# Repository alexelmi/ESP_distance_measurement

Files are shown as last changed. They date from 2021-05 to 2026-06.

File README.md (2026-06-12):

# Distance Measurement

A tiny handheld ultrasonic "distance radar" built on a WeMos D1 mini. The closer
you hold it to an object, the faster it blinks and beeps.

> This tiny project I made with my daughter. When she came to me asking for a
> little handheld which is peeping and blinking, I thought using an ultrasonic
> sensor could be fun.

So I sat down and designed the circuit and the PCB in KiCad:

| Schematic | PCB | 3D view |
|---|---|---|
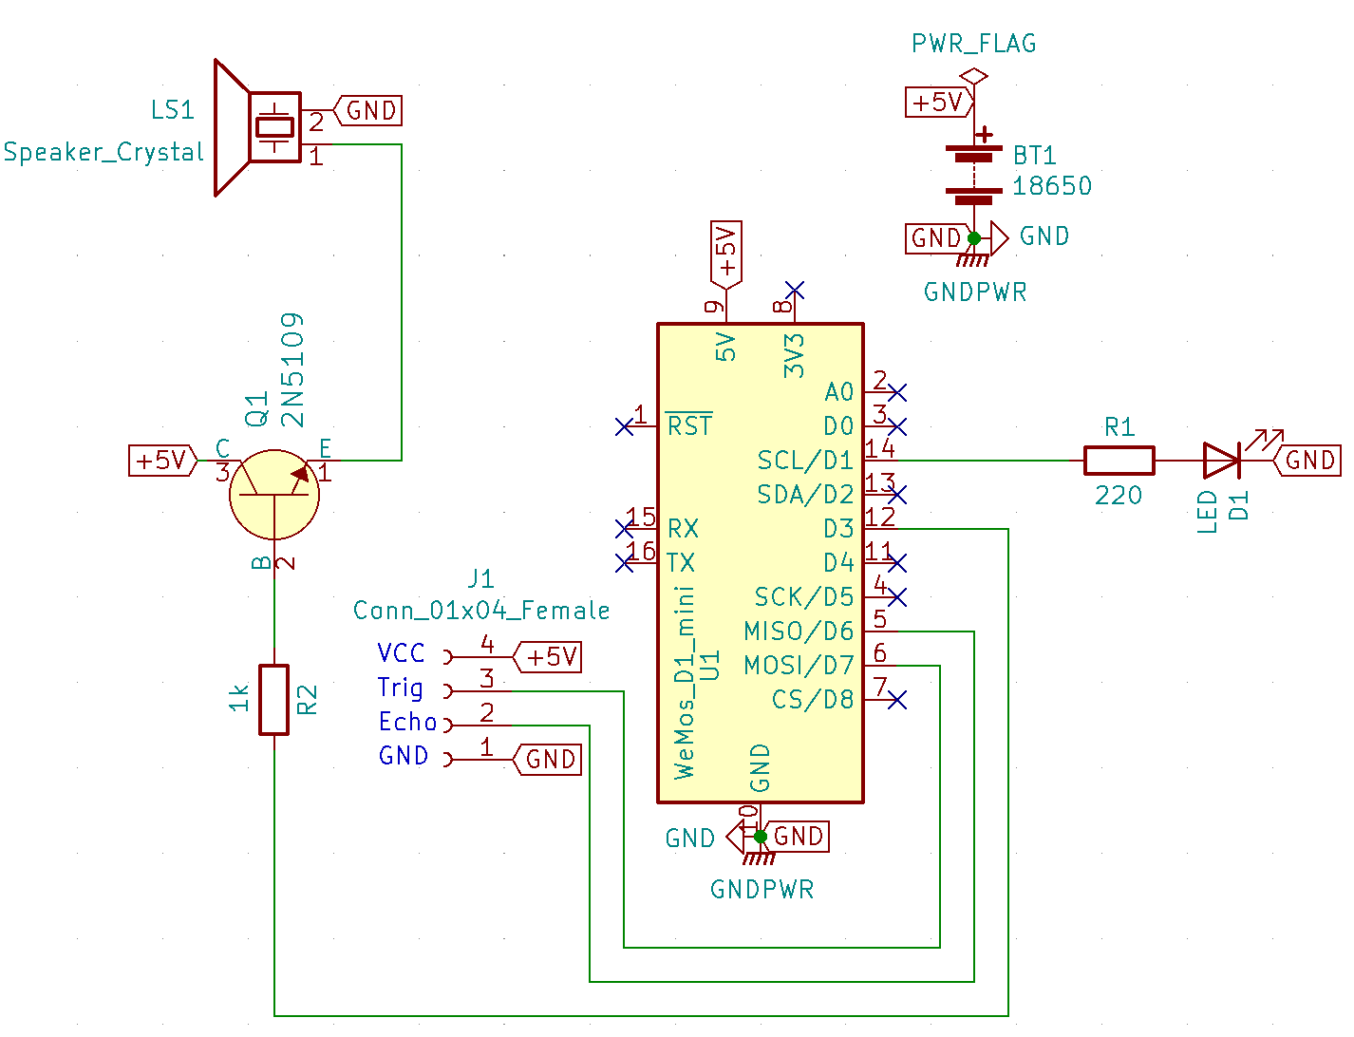
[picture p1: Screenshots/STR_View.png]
Schematic
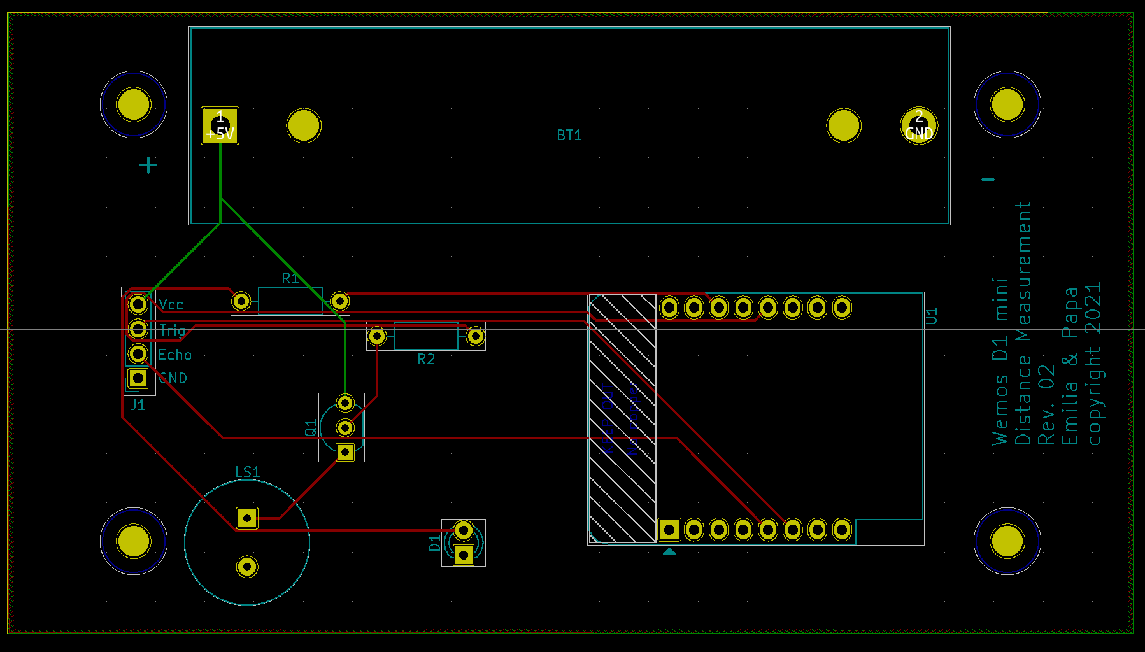
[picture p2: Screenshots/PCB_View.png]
PCB
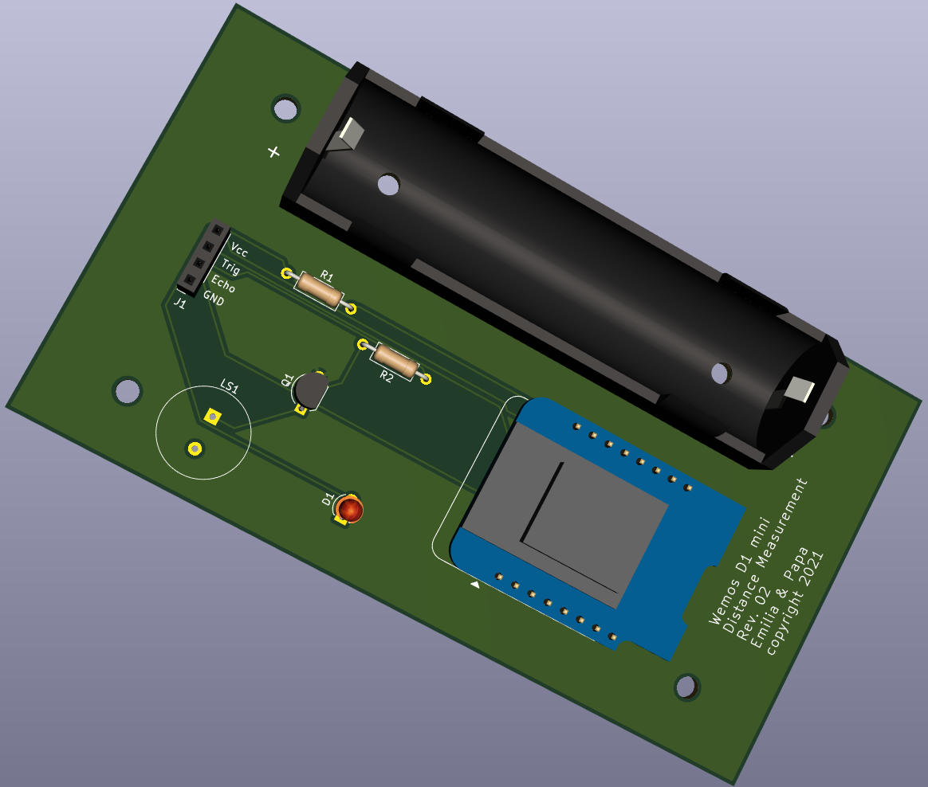
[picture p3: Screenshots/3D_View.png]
3D
|  |  |  |

The next day we put the components together and loaded the first test sketch onto
the WeMos D1 mini. (I have to admit I didn't test it before. 🙂)

## Features

- Ultrasonic distance measurement (~2 cm … 5 m) with an HC-SR04.
- LED + buzzer feedback that speeds up as the object gets closer; **solid** when
  very close and **silent** when nothing is in range.
- Distance also printed over `Serial` at 115200 baud.

## Hardware at a glance

| Function | WeMos label | ESP8266 GPIO |
|---|---|---|
| Ultrasonic Trigger | D7 | GPIO13 |
| Ultrasonic Echo | D6 | GPIO12 |
| LED | D1 | GPIO5 |
| Buzzer (via transistor) | D3 | GPIO0 |

Full BOM, schematic, PCB and Gerbers are in [`Hardware/`](Hardware/). Pin mapping
verified against the KiCad netlist.

## Software

The code was built up from small test sketches, then combined into the final
firmware:

- **Ultrasonic test sketch** — [`Software/Test_UltraSonic_Simple`](Software/Test_UltraSonic_Simple) — prints the measured distance.
- **LED blink test sketch** — [`Software/Test_LED_Simple`](Software/Test_LED_Simple).
- **Buzzer beep test sketch** — [`Software/Test_Buzzer_Simple`](Software/Test_Buzzer_Simple).
- **Final firmware** — [`Software/Final_Software`](Software/Final_Software) — sensor + LED + buzzer combined.

### Quick start

1. Install the Arduino IDE and add ESP8266 board support
   (`https://arduino.esp8266.com/stable/package_esp8266com_index.json`).
2. Select board **LOLIN(WEMOS) D1 R2 & mini**.
3. Open `Software/Final_Software/Final_Software.ino`, upload, and open the Serial
   Monitor at **115200 baud**.

Step-by-step instructions are in the [full documentation](docs/DOCUMENTATION.md).

## Tests

The firmware's distance/beep logic is unit-tested on the host (no hardware
needed):

```sh
cd Software/Tests
c++ -std=c++11 -Wall -Wextra test_distance_logic.cpp -o test_distance_logic
./test_distance_logic
```

## Documentation

- 📘 [Full documentation](docs/DOCUMENTATION.md) — theory, hardware, firmware,
  build & flash, troubleshooting.
- 🛠️ [Work report](WORK_REPORT.md) — bugs fixed and improvements made.
- ✅ [Tests README](Software/Tests/README.md).

## License

See [LICENSE](LICENSE).

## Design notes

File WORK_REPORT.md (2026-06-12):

# Work Report — Code review, fixes, tests & docs

This report documents a review-and-improvement pass over the
`ESP_distance_measurement` project: the bugs found, the changes made, the test
suite added, and the documentation written.

## 1. Scope

- Reviewed all firmware sketches under `Software/`.
- Cross-checked the firmware pin assignments against the hardware
  (`Hardware/KiCad_Files/Distance_Measurement_V2.net`).
- Implemented fixes and improvements.
- Added a host-side test suite and ran it.
- Wrote full documentation and rebuilt the README.

## 2. Bugs found & fixed

### 2.1 Continuous beeping when nothing is in range *(functional bug)*

`pulseIn()` returns `0` on timeout (no echo). The old `Final_Software` computed
`distanceCM = 0`, which fell into the `distanceCM <= 9` branch → `waiting = 0` →
the LED and buzzer were driven continuously. **Result:** the device beeped
non-stop whenever nothing was in front of it.

**Fix:** `echoToDistanceCm()` now returns a `NO_MEASUREMENT` sentinel for a
timeout or any reading outside ~2 cm…5 m, and `loop()` stays silent in that case.
Covered by a regression test.

### 2.2 Trigger pulse 1000× too long *(spec violation)*

The HC-SR04 expects a **10 µs** HIGH pulse on `TRIG`. Both the final and the
ultrasonic test sketch used `delay(10)` — i.e. **10 ms** — plus a leading
`delay(5)`. It happened to work but stretched every loop and is out of spec.

**Fix:** replaced with `delayMicroseconds(2)` / `delayMicroseconds(10)`, and gave
`pulseIn()` an explicit 30 ms timeout (~5 m) so a missing echo no longer blocks.

### 2.3 Wrong Echo pin in the ultrasonic test sketch *(hardware mismatch)*

`Test_UltraSonic_Simple` used `pinEcho = 15` (GPIO15). The KiCad netlist shows
GPIO15 is **not** wired to the sensor on this PCB — the sensor's Echo line is on
**GPIO12**. The test sketch therefore could not work on the actual board.

**Fix:** set `pinEcho = 12` to match the PCB, with a comment explaining why.

*(The `Final_Software` pin assignments — Trig 13, Echo 12, LED 5, Buzzer 0 — were
verified **correct** against the netlist and left unchanged.)*

## 3. Improvements

- **Replaced the ~60-line if/else ladder** that mapped distance → beep interval
  with a compact, ordered lookup table (`distanceToWaitingMs()`), removing the
  repeated `Serial.print` blocks and any risk of coverage gaps.
- **Extracted the pure logic** into `Software/Final_Software/distance_logic.h`
  (no Arduino dependencies) so the maths is unit-testable on a PC. The sketch
  `#include`s it.
- **"Very close" now means a solid tone/light** instead of `waiting = 0`, which
  previously toggled with no delay and was effectively invisible.
- **Named constants** for the speed of sound, valid range and echo timeout.
- Minor cleanups: consistent naming (`buzzerPin`), `digitalWrite(TRIG, LOW)` in
  `setup()`, float division in the distance maths, trailing newlines.

## 4. Tests

Added `Software/Tests/test_distance_logic.cpp` — a dependency-free C++ test
runner that exercises the exact firmware logic on the host.

```
$ c++ -std=c++11 -Wall -Wextra test_distance_logic.cpp -o test_distance_logic
$ ./test_distance_logic
...
21 checks, 0 failure(s)
ALL TESTS PASSED
```

Coverage: echo→distance conversion, the timeout/out-of-range regression cases,
every row of the distance→interval table, and a monotonicity property (the beep
interval never increases as the target gets closer).

## 5. Documentation

- **`docs/DOCUMENTATION.md`** — full project documentation: overview, theory of
  operation, BOM, verified pin-mapping table, schematic/PCB/3D images, firmware
  guide, build & flash steps, the beep-interval table, tests, and
  troubleshooting.
- **`Software/Tests/README.md`** — how to build and run the tests.
- **`readme.md`** — rebuilt: keeps the original story and adds features,
  hardware summary, quick start, and links to the docs and tests.
- **`.gitignore`** — ignores the compiled test binary.

## 6. Files changed / added

| File | Change |
|---|---|
| `Software/Final_Software/Final_Software.ino` | Rewritten (fixes + refactor) |
| `Software/Final_Software/distance_logic.h` | **New** — testable pure logic |
| `Software/Test_UltraSonic_Simple/Test_UltraSonic_Simple.ino` | Echo pin + trigger timing fix |
| `Software/Tests/test_distance_logic.cpp` | **New** — unit tests |
| `Software/Tests/README.md` | **New** |
| `docs/DOCUMENTATION.md` | **New** |
| `WORK_REPORT.md` | **New** — this file |
| `readme.md` | Rebuilt |
| `.gitignore` | Ignore test binary |

## 7. Not changed (and why)

- **Hardware files** (KiCad, Gerbers, PDFs, Fritzing) — out of scope; the review
  only used them to verify pin assignments.
- **`Final_Software` pin numbers** — already correct per the netlist.
- The firmware could not be compiled with `arduino-cli` (not installed in this
  environment); correctness was instead verified through the host-side tests of
  the extracted logic.

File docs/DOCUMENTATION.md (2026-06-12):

# ESP Distance Measurement — Full Documentation

A small handheld ultrasonic "distance radar" built on a WeMos D1 mini (ESP8266).
The closer an object is, the faster an LED blinks and a buzzer beeps. It started
as a weekend project to build together with my daughter.

- [1. Overview](#1-overview)
- [2. How it works](#2-how-it-works)
- [3. Hardware](#3-hardware)
  - [3.1 Bill of materials](#31-bill-of-materials)
  - [3.2 Pin mapping](#32-pin-mapping)
  - [3.3 Schematic, PCB and 3D view](#33-schematic-pcb-and-3d-view)
- [4. Firmware](#4-firmware)
  - [4.1 Sketches](#41-sketches)
  - [4.2 Distance → beep interval](#42-distance--beep-interval)
  - [4.3 Build & flash](#43-build--flash)
- [5. Tests](#5-tests)
- [6. Troubleshooting](#6-troubleshooting)
- [7. Changes & fixes](#7-changes--fixes)

---

## 1. Overview

| | |
|---|---|
| **Microcontroller** | WeMos D1 mini (ESP8266) |
| **Sensor** | HC-SR04 ultrasonic range finder |
| **Outputs** | LED + piezo buzzer (driven via an NPN transistor) |
| **Range** | ~2 cm … 5 m |
| **Power** | 5 V (battery `BT1` / USB) |
| **Firmware** | Arduino sketch, `Serial` at 115200 baud |

The behaviour: every loop the firmware fires one ultrasonic ping, converts the
echo time to a distance, and translates that distance into a blink/beep
interval. Far away → slow beep. Very close → solid tone. Nothing in range →
silent.

## 2. How it works

An HC-SR04 measures distance by emitting a 40 kHz ultrasonic burst and timing
how long the echo takes to return:

1. The MCU pulses `TRIG` HIGH for **10 µs**.
2. The sensor emits 8 ultrasonic cycles and raises `ECHO`.
3. `ECHO` stays HIGH for the round-trip travel time of the sound.
4. Distance = `(echo_time / 2) × speed_of_sound`.

With the speed of sound ≈ 343.2 m/s = **0.03432 cm/µs**:

```
distance_cm = (echo_time_µs / 2) × 0.03432
```

If no echo returns, `pulseIn()` times out and returns `0`. The firmware treats
that (and any reading outside ~2 cm…5 m) as **"no measurement"** and stays quiet,
rather than mistaking it for a zero-centimetre object.

## 3. Hardware

### 3.1 Bill of materials

| Ref | Part | Notes |
|-----|---|---|
| `U1` | WeMos D1 mini (ESP8266) | Main controller |
| `J1` | 4-pin header | HC-SR04 connector: GND / Echo / Trig / 5V |
| `D1` | LED | Visual indicator |
| `R1` | Resistor | LED series resistor |
| `Q1` | NPN transistor | Buzzer driver |
| `R2` | Resistor | Transistor base resistor |
| `LS1` | Piezo buzzer (PS1240) | Audible indicator |
| `BT1` | Battery / 5 V supply | Power input |

*(Refs taken from the KiCad netlist `Hardware/KiCad_Files/Distance_Measurement_V2.net`.)*

### 3.2 Pin mapping

Verified against the KiCad netlist. **Use these in the firmware.**

| Function | WeMos label | ESP8266 GPIO | Driven via |
|---|---|---|---|
| Ultrasonic **Trigger** | D7 | **GPIO13** | direct to `J1` |
| Ultrasonic **Echo** | D6 | **GPIO12** | direct from `J1` |
| **LED** | D1 | **GPIO5** | `R1` |
| **Buzzer** | D3 | **GPIO0** | `R2` → `Q1` → `LS1` |

> **Note on GPIO0 (buzzer):** GPIO0 is a boot-strapping pin on the ESP8266. It
> must be HIGH at power-up to boot from flash. The transistor base sits behind
> `R2`, so the pin is free to float high at boot — but if you ever rewire the
> buzzer, keep this constraint in mind.

> **Note on the HC-SR04 connector `J1`:** the header order is
> `GND · Echo(GPIO12) · Trig(GPIO13) · 5V`. Make sure the sensor is plugged in
> with matching orientation (sensor pinout is `VCC · Trig · Echo · GND`).

### 3.3 Schematic, PCB and 3D view

| Schematic | PCB | 3D |
|---|---|---|
| Schematic | PCB | 3D |

Source files:
- KiCad project: `Hardware/KiCad_Files/`
- Gerbers (V2): `Hardware/Gerber_Distance_Measurement_V2/`
- Circuit diagram PDFs: `Hardware/Circuit Diagram/`
- Interactive BOM: `Hardware/bom/ibom.html`
- Fritzing layout: `Hardware/Fritzing/`

## 4. Firmware

### 4.1 Sketches

| Sketch | Purpose |
|---|---|
| `Software/Test_LED_Simple/` | Blink the LED only (GPIO5). |
| `Software/Test_Buzzer_Simple/` | Beep the buzzer only (GPIO0). |
| `Software/Test_UltraSonic_Simple/` | Print measured distance over `Serial`. |
| `Software/Final_Software/` | The complete device (sensor + LED + buzzer). |

The final sketch keeps its pure logic in
[`distance_logic.h`](../Software/Final_Software/distance_logic.h) so it can be
unit-tested off-device (see [Tests](#5-tests)).

### 4.2 Distance → beep interval

`distanceToWaitingMs()` maps a distance to the LED/buzzer half-period:

| Distance (cm) | Half-period (ms) | Feel |
|---:|---:|---|
| 400 … 500 | 1000 | very slow |
| 300 … 399 | 800 | |
| 200 … 299 | 700 | |
| 100 … 199 | 500 | |
| 80 … 99 | 400 | |
| 60 … 79 | 300 | |
| 40 … 59 | 200 | |
| 20 … 39 | 100 | |
| 10 … 19 | 50 | fast |
| 2 … 9 | 0 | **solid** tone/light |
| no echo / >5 m | — | **silent** |

### 4.3 Build & flash

1. Install the [Arduino IDE](https://www.arduino.cc/en/software).
2. Add ESP8266 board support: **File → Preferences → Additional Boards Manager
   URLs** → `https://arduino.esp8266.com/stable/package_esp8266com_index.json`,
   then install **esp8266** in the Boards Manager.
3. Select board **LOLIN(WEMOS) D1 R2 & mini**.
4. Open `Software/Final_Software/Final_Software.ino`.
5. Upload, then open the Serial Monitor at **115200 baud**.

## 5. Tests

The conversion and mapping logic is covered by host-side unit tests — no
hardware required:

```sh
cd Software/Tests
c++ -std=c++11 -Wall -Wextra test_distance_logic.cpp -o test_distance_logic
./test_distance_logic
```

See [`Software/Tests/README.md`](../Software/Tests/README.md) for what is
covered.

## 6. Troubleshooting

| Symptom | Likely cause |
|---|---|
| Always "No reading" | Echo not on GPIO12 / sensor connector reversed / no 5 V to sensor. |
| Device beeps non-stop with nothing in front | Old firmware (pre-fix). Reflash the current `Final_Software`. |
| Board won't boot / hangs at power-up | Something holding GPIO0 LOW at boot (buzzer wiring). |
| Distances jump around | Soft/angled/small targets reflect poorly; aim at a flat surface. |
| Nothing on Serial | Wrong baud rate — set the monitor to 115200. |

## 7. Changes & fixes

A detailed log of the bug fixes and improvements made to the firmware is in
[`WORK_REPORT.md`](../WORK_REPORT.md).

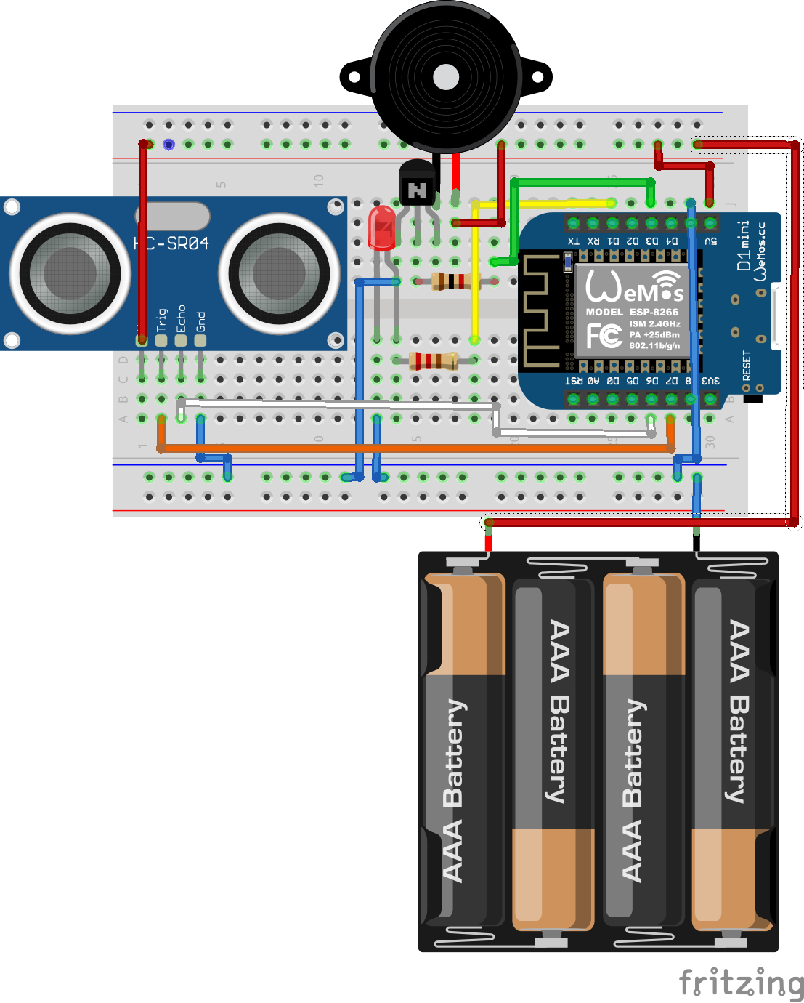
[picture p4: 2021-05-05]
Hardware/Fritzing/Layout.png

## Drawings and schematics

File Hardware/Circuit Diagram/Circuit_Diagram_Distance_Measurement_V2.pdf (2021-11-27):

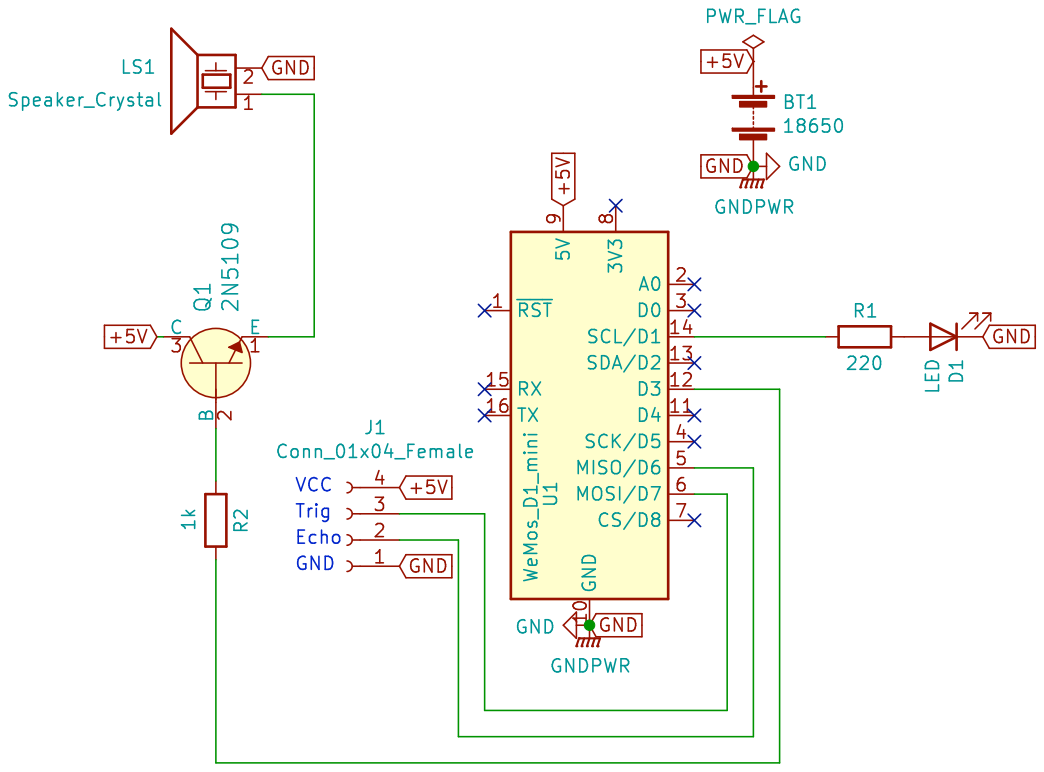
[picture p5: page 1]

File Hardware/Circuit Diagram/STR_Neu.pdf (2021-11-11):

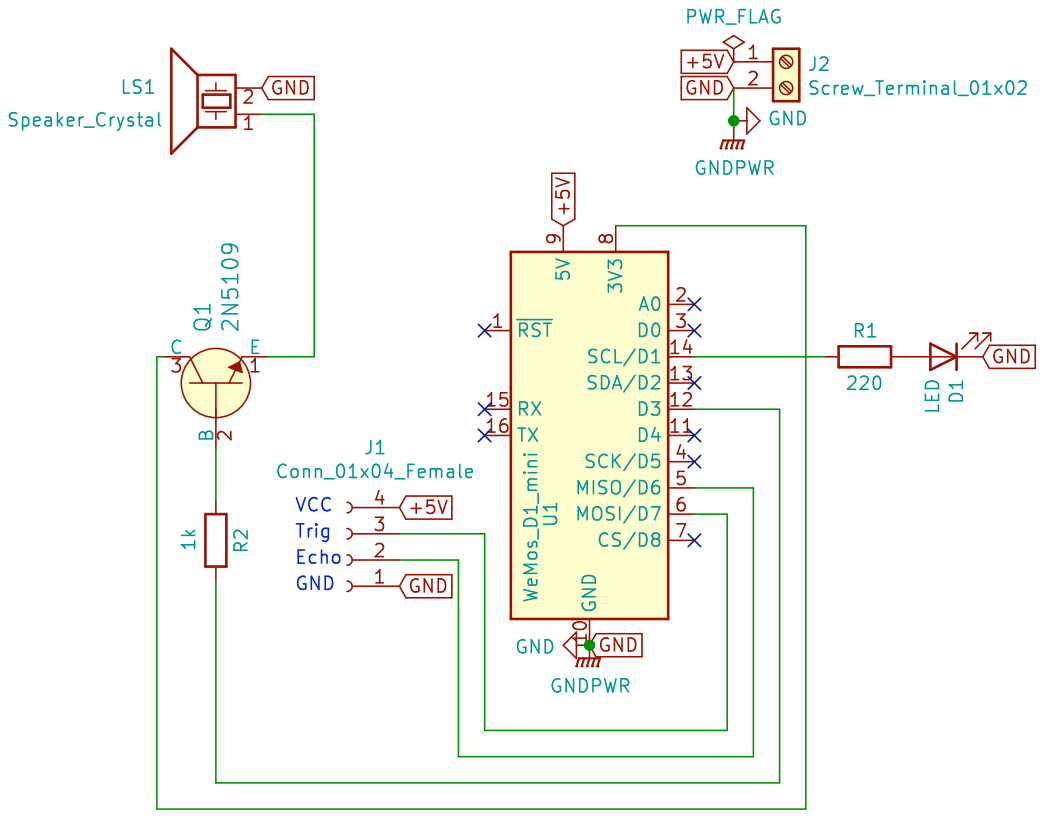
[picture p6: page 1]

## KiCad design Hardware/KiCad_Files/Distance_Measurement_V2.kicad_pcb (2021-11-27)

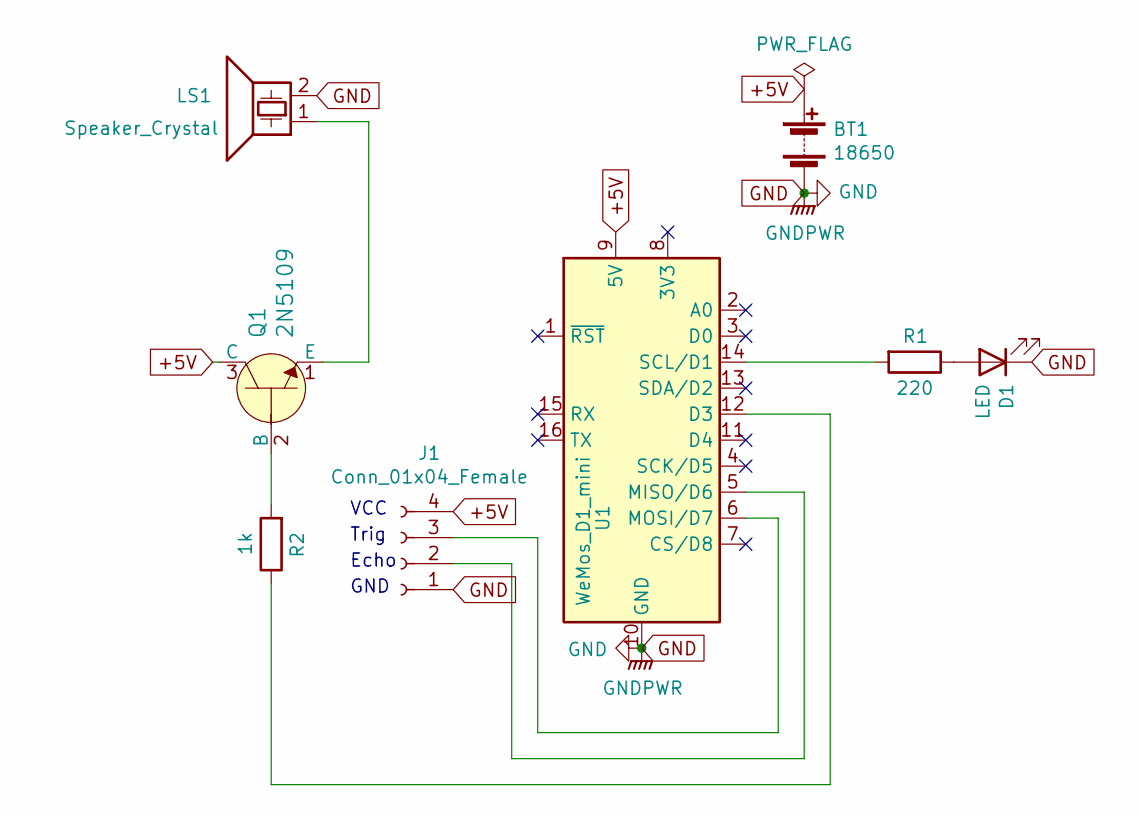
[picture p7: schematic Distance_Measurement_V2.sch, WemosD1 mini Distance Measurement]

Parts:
BT1: 18650; BatteryHolder_MPD_BH-18650-PC2
D1: LED; LED_D3.0mm
J1: Conn_01x04_Female; PinSocket_1x04_P2.54mm_Vertical
LS1: Speaker_Crystal; Piezo_Transducer_THT_PS1240P02BT
Q1: 2N5109; TO-92_Inline_Wide; MPN 2N5109; Digi-Key_PN 2N5109CS-ND
R1: 220; R_Axial_DIN0207_L6.3mm_D2.5mm_P10.16mm_Horizontal
R2: 1k; R_Axial_DIN0207_L6.3mm_D2.5mm_P10.16mm_Horizontal
U1: WeMos_D1_mini; WEMOS_D1_mini_light

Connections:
+5V: BT1.1 (+), J1.4, Q1.3 (C), U1.9 (5V)
GND: BT1.2 (-), D1.1 (K), J1.1, LS1.2, U1.10 (GND)
unnamed: D1.2 (A), R1.1
unnamed: J1.2, U1.5 (MISO/D6)
unnamed: J1.3, U1.6 (MOSI/D7)
unnamed: LS1.1, Q1.1 (E)
unnamed: Q1.2 (B), R2.2
unnamed: R1.2, U1.14 (SCL/D1)
unnamed: R2.1, U1.12 (D3)

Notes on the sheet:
VCC
Trig
Echo
GND

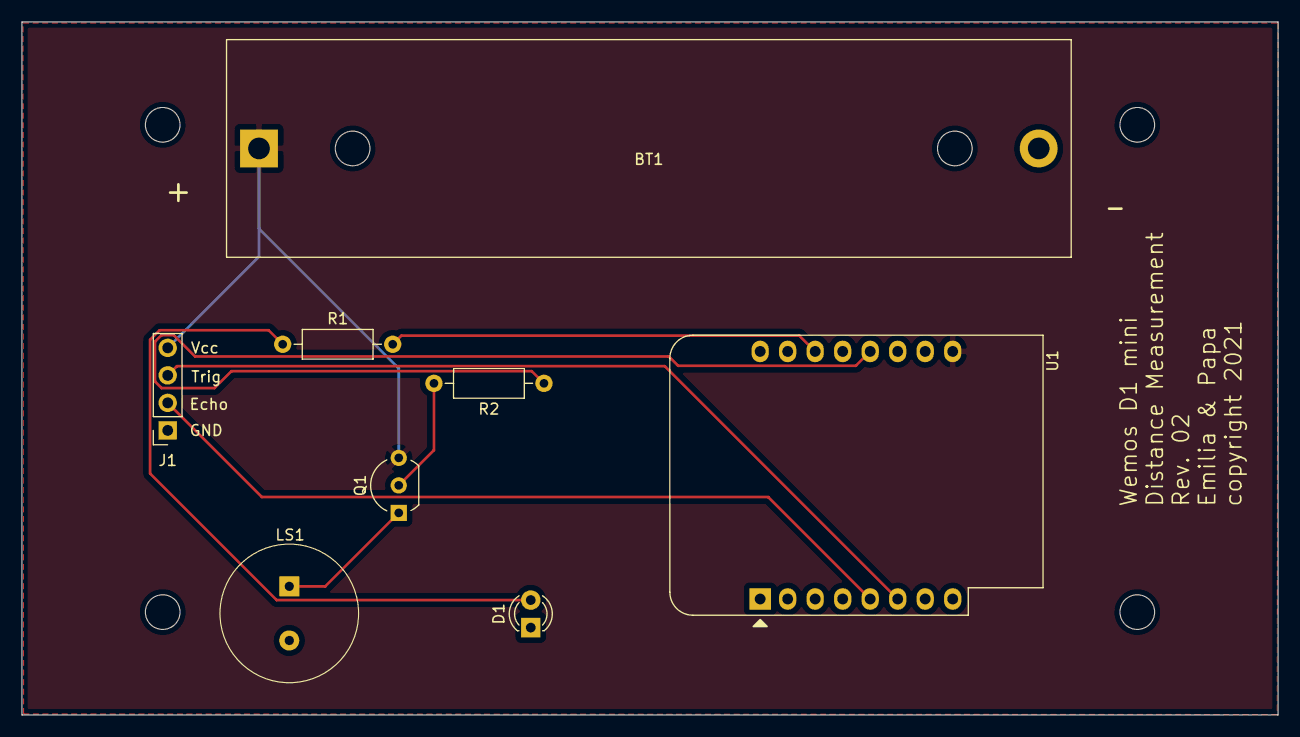
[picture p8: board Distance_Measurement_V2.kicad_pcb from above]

Board: 2 copper layers, 116.0 x 64.0 mm, 8 parts (0 on the bottom side), 9 nets.

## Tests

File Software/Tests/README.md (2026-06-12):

# Host-side tests

The distance/beep logic of the firmware lives in
[`../Final_Software/distance_logic.h`](../Final_Software/distance_logic.h) and
is intentionally free of Arduino calls. That means it can be compiled and run on
a normal computer, so the maths and the bug fixes are verified **without any
hardware**.

## Run the tests

```sh
cd Software/Tests
c++ -std=c++11 -Wall -Wextra test_distance_logic.cpp -o test_distance_logic
./test_distance_logic
```

Expected result: `ALL TESTS PASSED` (exit code 0).

## What is covered

- **Echo → distance conversion** (`echoToDistanceCm`), including the regression
  test for the old bug where a `pulseIn()` timeout (`0 µs`) was treated as `0 cm`
  and made the device beep continuously when nothing was in range.
- **Out-of-range handling** — readings below ~2 cm or beyond ~5 m are reported as
  "no measurement".
- **Distance → beep interval mapping** (`distanceToWaitingMs`) for every step of
  the table.
- **Monotonicity** — the beep interval never increases as the target gets closer.

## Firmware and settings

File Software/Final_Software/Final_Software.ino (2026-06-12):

// Ultrasonic distance meter for the WeMos D1 mini (ESP8266).
// A closer object makes the LED blink and the buzzer beep faster; when nothing
// is in range the device stays quiet.
//
// Pin mapping verified against the KiCad netlist (Hardware/KiCad_Files):
//   Trigger -> GPIO13 (D7)            Echo                  -> GPIO12 (D6)
//   LED     -> GPIO5  (D1), via R1    Buzzer (via Q1 + R2)  -> GPIO0  (D3)
//
// The distance/interval logic lives in distance_logic.h so it can be unit
// tested on a PC (see ../Tests).

#include "distance_logic.h"

const int pinTrigger = 13;
const int pinEcho    = 12;
const int ledPin     = 5;
const int buzzerPin  = 0;

// pulseIn() timeout in microseconds. 30 ms ~= 5 m round trip; this caps the
// loop time when there is no echo instead of blocking for a full second.
const unsigned long ECHO_TIMEOUT_US = 30000UL;

void setup()
{
  Serial.begin(115200);
  pinMode(pinTrigger, OUTPUT);
  pinMode(pinEcho, INPUT);
  pinMode(ledPin, OUTPUT);
  pinMode(buzzerPin, OUTPUT);
  digitalWrite(pinTrigger, LOW);
}

// Fire one 10 us trigger pulse and return the echo width in microseconds.
// HC-SR04 expects a 10 us HIGH pulse on TRIG; the previous version used
// delay() (milliseconds) which was 1000x too long.
long measureEchoUs()
{
  digitalWrite(pinTrigger, LOW);
  delayMicroseconds(2);
  digitalWrite(pinTrigger, HIGH);
  delayMicroseconds(10);
  digitalWrite(pinTrigger, LOW);
  return pulseIn(pinEcho, HIGH, ECHO_TIMEOUT_US);
}

// One blink/beep cycle. waitMs == 0 means "very close" -> solid tone/light.
void signalDistance(int waitMs)
{
  if (waitMs <= 0) {
    digitalWrite(ledPin, HIGH);
    digitalWrite(buzzerPin, HIGH);
    delay(100);
    return;
  }
  digitalWrite(ledPin, HIGH);
  digitalWrite(buzzerPin, HIGH);
  delay(waitMs);
  digitalWrite(ledPin, LOW);
  digitalWrite(buzzerPin, LOW);
  delay(waitMs);
}

void loop()
{
  long distanceCM = echoToDistanceCm(measureEchoUs());

  if (distanceCM == NO_MEASUREMENT) {
    Serial.println("No reading");
    digitalWrite(ledPin, LOW);
    digitalWrite(buzzerPin, LOW);
    delay(200);                 // idle quietly, then measure again
    return;
  }

  Serial.print(distanceCM);
  Serial.println(" cm");
  signalDistance(distanceToWaitingMs(distanceCM));
}

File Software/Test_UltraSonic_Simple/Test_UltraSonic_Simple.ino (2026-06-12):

//thanks to https://www.smarthome-tricks.de/esp8266/mit-dem-ultraschallsensor-entfernungen-messen/

// Pins must match the PCB: TRIG -> GPIO13 (D7), ECHO -> GPIO12 (D6).
// (The original sketch used GPIO15 for ECHO, which is not wired to the sensor
// on this board - see Hardware/KiCad_Files netlist.)
const int pinTrigger = 13;
const int pinEcho = 12;

long duration = 0;
long distanceCM = 0;

void setup()
{
  Serial.begin (115200);
  pinMode(pinTrigger, OUTPUT);
  pinMode(pinEcho, INPUT);
  digitalWrite(pinTrigger, LOW);
}

void loop()
{
  // HC-SR04 trigger: a 10 microsecond HIGH pulse (not milliseconds!).
  digitalWrite(pinTrigger, LOW);
  delayMicroseconds(2);
  digitalWrite(pinTrigger, HIGH);
  delayMicroseconds(10);
  digitalWrite(pinTrigger, LOW);

  duration = pulseIn(pinEcho, HIGH, 30000UL);  // 30 ms timeout (~5 m)
  distanceCM = (duration / 2.0) * 0.03432;
  if (duration == 0 || distanceCM >= 500 || distanceCM <= 0)
  {
    Serial.println("Kein Messwert");
  }
  else
  {
    Serial.print(distanceCM);
    Serial.println(" cm");
  }
  delay(1000);
}

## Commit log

2021-05-05 updated layout with battery
    [Layout.fzz]
2021-10-17 Update and KiCAD Files
    [Distance_Measurement-B_Cu.gbr, Distance_Measurement-B_Mask.gbr, Distance_Measurement-B_Paste.gbr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]
2021-11-11 fixed a twisted GND/Vcc signal at PCB
    [Distance_Measurement-B_Cu.gbr, Distance_Measurement-B_Mask.gbr, Distance_Measurement-B_Paste.gbr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]
2021-11-11 corrected failure on PCB
    [Distance_Measurement-B_Cu.gbr, Distance_Measurement-B_Mask.gbr, Distance_Measurement-B_Paste.gbr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]
2021-11-11 update of Gerber
    [Distance_Measurement-B_Cu.gbr, Distance_Measurement-B_Mask.gbr, Distance_Measurement-B_Paste.gbr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]
2021-11-27 added Version 2
    including a battery holder for 18650
    [Distance_Measurement.kicad_pcb, Distance_Measurement_ALT.kicad_pcb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]
2026-06-12 Fix firmware bugs, refactor logic, add tests and documentation
    Firmware fixes:
    - Final_Software: treat pulseIn timeout / out-of-range as "no reading"
    instead of 0 cm, which previously made the device beep continuously
    when nothing was in range.
    - Use delayMicroseconds() for the 10 us HC-SR04 trigger pulse instead of
    delay() (was 1000x too long); add an explicit echo timeout.
    - Test_UltraSonic_Simple: fix Echo pin to GPIO12 to match the PCB
    (was GPIO15, which is not wired to the sensor per the KiCad netlist).
    Refactor:
    - Extract pure distance/beep logic into distance_logic.h (Arduino-free,
    unit-testable); replace the long if/else ladder with a lookup table.
    - "Very close" now gives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
    [Final_Software.ino, Test_UltraSonic_Simple.ino]

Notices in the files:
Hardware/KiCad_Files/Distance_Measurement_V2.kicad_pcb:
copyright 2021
